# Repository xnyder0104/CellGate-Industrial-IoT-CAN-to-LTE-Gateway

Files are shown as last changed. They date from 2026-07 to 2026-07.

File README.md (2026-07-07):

# CellGate: Industrial IoT CAN-to-LTE Gateway

## Project Overview

This project is a compact, reliable, and manufacturable 2-layer custom PCB designed to bridge physical CAN bus networks with cloud infrastructure via cellular telemetry. Operating in harsh embedded environments, such as automotive engine bays or industrial factory floors, requires highly robust hardware. Power fluctuations, electrical noise, and Electrostatic Discharge (ESD) events can easily destroy standard development boards or cause critical communication failures.

To overcome these challenges, CellGate utilizes an STM32 ARM Cortex-M0+ microcontroller paired with a Quectel EC200U LTE Cat-1 module to handle high-speed data processing and transmission. The board integrates an industrial power path, strictly isolated voltage domains, multi-stage hardware protection, and a seamless load-sharing battery backup system, ensuring uninterrupted diagnostic data flow.

## Key Features & Engineering Highlights

* **Advanced Power Path Management:** Implements a PMV65XP MOSFET-based load-sharing architecture that automatically and seamlessly switches between a high-voltage external DC input (up to 40V) and a Lithium-ion battery backup without resetting the system.
* **Strict Voltage Domain Isolation:** A TXB0104 bidirectional logic level shifter protects the sensitive 1.8V Quectel silicon from the 3.3V STM32 logic signals, enabling safe, high-speed full-duplex UART transmission.
* **Fail-Safe Boot Design:** Integrates a hardware-level 10k-ohm pull-down resistor on the STM32 BOOT0 (PA14) pin to prevent the MCU from accidentally entering DFU Bootloader Mode due to ambient electrical noise during battery-only field operation.
* **Multi-Stage ESD Armor:** Deploys hardware protection across all external interfaces, including PESD2CAN TVS diodes on the differential bus lines and USBLC6 protection on the Type-C port.
* **Selectable Bus Termination:** Includes a physical jumper header for selectable 120-ohm CAN bus termination, making the board adaptable for end-of-line or mid-bus installations.
* **Comprehensive Diagnostic UI:** A dedicated 9-LED onboard panel provides immediate visual debugging for Main Power, Battery Charging, Battery Full, MCU Status, LTE Network Status, GPS Fix, CAN Activity, UART Activity, and Hardware Errors/Faults.

## Hardware Architecture & Working Principle

### 1. Power Supply & Battery Protection (+V_SYS)
* **HV Step-Down:** An LMR14030 buck converter steps down raw industrial inputs (up to 40V) to a stable 5V rail.
* **Voltage Regulation:** The master +V_SYS net feeds two independent LDOs: an AMS1117 generating the 3.3V MCU domain, and a TLV70218 generating the 1.8V modem reference domain.
* **Battery Circuitry:** A TP4056 linear charger manages Li-ion charging. It is paired with a strictly low-side DW01A controller and dual FS8205A MOSFETs, which continuously monitor the cell and isolate the battery ground instantly if over-charge, over-discharge, or a dead-short is detected.

### 2. Core Processing & Connectivity
* **Microcontroller Logic:** The STM32G0B1CBT6 handles all data preprocessing, CAN-to-UART conversion, and LED status mapping. 
* **Cellular & GNSS:** The Quectel EC200U module executes AT commands for LTE telemetry and GNSS location tracking. It is powered directly from the high-current battery rail (+V_BAT) to sustain 2-Amp transmission bursts safely.
* **CAN Interface:** An SN65HVD230 transceiver safely translates high-voltage automotive differential CAN signals down to the 3.3V logic level required by the STM32.

### 3. Debugging & Firmware Interfaces
* **SWD Programming:** Standard 5-pin SWD interface (SWDIO, SWCLK, NRST, +3.3V, GND) for flashing the STM32.
* **Hardware UART:** An exposed 4-pin hardware UART header operating strictly at 1.8V (VDD_EXT) for direct, low-level Quectel modem diagnostics.
* **USB Type-C:** Directly exposes the EC200U USB interface for cellular firmware upgrades and advanced module diagnostics.

## PCB Layout & Manufacturing Strategy

The board was meticulously routed as a 2-layer PCB, optimizing for low parasitic inductance, signal integrity, and manufacturability:

* **Solid Ground Plane:** The entire bottom layer is maintained as an unbroken solid copper ground plane to absorb the massive switching noise of the LMR14030 buck converter and provide a clean return path for RF signals.
* **Bottom-Layer Decoupling:** To minimize trace length and parasitic inductance, critical decoupling capacitors for the STM32 and Quectel EC200U are placed directly underneath the component pins on the bottom layer, fed by localized via stitching.
* **45-Degree Mitered Routing:** All high-speed data lines (6-mil trace width) utilize clean 45-degree cornering, avoiding 90-degree right angles and acute acid traps to ensure perfect chemical etching during manufacturing.
* **RF Trace Geometry:** 50-ohm controlled impedance traces are routed cleanly from the modem RF pads directly to the U.FL edge connectors, completely avoiding vias to prevent signal reflection.

## Applications

* Heavy machinery and fleet management telemetry (CAN bus diagnostics).
* Remote industrial equipment monitoring and predictive maintenance.
* Standalone IoT sensor gateways for off-grid environmental tracking.
* High-reliability telemetry nodes requiring uninterruptible power supplies (UPS).

## Future Scope

* **Mechanical Enclosure Design:** Utilizing the exported 3D .step files to design a custom, IP67-rated waterproof housing for harsh outdoor deployments.
* **Firmware Over-The-Air (FOTA):** Implementing a custom MCU bootloader to download, verify, and flash firmware updates seamlessly via the Quectel LTE connection.
* **Onboard Sensor Expansion:** Integrating standard I2C/SPI environmental sensors (e.g., temperature, humidity, accelerometer) directly onto the motherboard for localized physical diagnostics.

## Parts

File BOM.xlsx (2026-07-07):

Reference Designators | Quantity | Description | Package | Value | Top/Bottom
 | 1 | Board | Board
C1, C25 | 2 | Capacitor - Generic | CAPC1005X60 | 10uF | Top
C23, C24, C26 | 3 | Capacitor - Generic | CAPC1005X61 | 10uF | Bottom
C2 | 1 | Capacitor - Generic | CAPC1608X85 | 100uF | Bottom
C3 | 1 | Capacitor - Generic | CAPC1608X85 | 100nf | Bottom
C4 | 1 | Capacitor - Generic | CAPC1608X85 | 33pF | Bottom
C5 | 1 | Capacitor - Generic | CAPC1608X85 | 10pF | Bottom
C22 | 1 | Capacitor - Generic | CAPC1005X60 | 0.1uF | Bottom
C6 | 1 | Capacitor - Generic | CAPC1005X60 | 0.1uF | Top
C7 | 1 | Capacitor - Generic | CAPC1005X60 | 22uF | Top
C8 | 1 | Capacitor - Generic | CAPC1005X60 | 0.01uF | Top
C9, C10, C13, C14 | 4 | Capacitor - Generic | CAPC1005X60 | NC | Top
C11 | 1 | Capacitor - Generic | CAPC1005X60 | 1uF | Bottom
C12 | 1 | Capacitor - Generic | CAPC1005X60 | 2.2uF | Bottom
C15, C16, C18 | 3 | Capacitor - Generic | CAPC1005X60 | 100nF | Bottom
C17, C20, C21 | 3 | Capacitor - Generic | CAPC1005X61 | 100nF | Top
C19 | 1 | Capacitor - Generic | CAPC1005X60 | 4.7uF | Bottom
D1, D5, D7, D8, D9, D10, D11 | 7 | Green LED - Generic | LEDC1608X65N_RND-G | CHIP-ROUND-G_0603 | Top
D2, D12 | 2 | Red LED - Generic | LEDC1608X65N_RND-R | CHIP-ROUND-R_0603 | Top
D3 | 1 | Schottky Diode | SS26 | SS26 | Top
D13 | 1 | Schottky Diode | SS26 | SS26 | Bottom
D4 | 1 | 600-watt TVS diode | DIOM5436X261N | SMBJ48A | Top
D6 | 1 | B340A-13-F | DIOM5226X240N | B340A-13-F | Top
F1 | 1 | Polymeric positive temperature coefficient (PPTC) resettable fuse | FUSE_1812L05060_LTF | 1812L050FUSE | Top
J1, J3 | 2 | RF connector receptacle | HIROSE_U.FL-R-SMT(10) | U.FL-R-SMT(10) | Top
J2 | 1 | Female USB Type-C receptacle | SHOUHAN_TYPE-C_16PIN_2MD_(073) | TYPE-C | Top
J4 | 1 | micro SIM card connector | GCT_SIM7100-6-1-15-00-A_REVC2 | SIM7100-6-1-15-00-A_REVC2 | Top
JP1 | 1 | Pin Header | 1X04 | PINHD-1X4 | Top
JP2 | 1 | Pin Header | 1X05 | PINHD-1X5 | Top
JP3 | 1 | Pin Header | 1X02 | PINHD-1X2 | Top
L1 | 1 | Bourns SRN8040 Series Type SMD Shielded Wire-wound SMD Inductor with a Ferrite Core, 10 uH +/-20% Semi-Shielded 3.1A Idc | SRN8040100M | SRN8040-100M | Top
P1, P2 | 2 | 2-pin screw terminal | TE_282837-2 | 282837-2 | Top
Q1 | 1 | NPN BJT | TO92127P495H495-3 | 2N3904 | Top
Q2 | 1 | N-channel MOSFET | SOT-23-6L_TCP | FS8205ASOT-23-6L_TCP | Bottom
Q3 | 1 | P-channel MOSFET | SOT95P230X110-3N | PMV65XP,215 | Bottom
R1, R2, R6, R13, R15, R16, R17, R18, R19, R21 | 10 | Resistor Fixed - ANSI | RESC1005X40 | 1k | Top
R3 | 1 | Resistor Fixed - ANSI | RESC1005X40 | 68k | Top
R4 | 1 | Resistor Fixed - ANSI | RESC1005X40 | 12k | Top
R5, R7 | 2 | Resistor Fixed - ANSI | RESC1005X40 | 100k | Top
R25 | 1 | Resistor Fixed - ANSI | RESC1005X41 | 100k | Bottom
R14, R22, R26 | 3 | Resistor Fixed - ANSI | RESC1005X40 | 10k | Top
R8 | 1 | Resistor Fixed - ANSI | RESC1005X41 | 10k | Bottom
R11 | 1 | Resistor Fixed - ANSI | RESC1005X40 | 5.1k | Top
R9 | 1 | Resistor Fixed - ANSI | RESC1005X41 | 5.1k | Bottom
R10, R12 | 2 | Resistor Fixed - ANSI | RESC1005X40 | 0 | Top
R20 | 1 | Resistor Fixed - ANSI | RESC1005X40 | 100 | Top
R23 | 1 | Resistor Fixed - ANSI | RESC1005X40 | 120 | Top
R24 | 1 | Resistor Fixed - ANSI | RESC1005X40 | 1.2k | Bottom
S1 | 1 | ESD Protection for CAN | DIO_PESD2CAN,215 | PESD2CAN,215 | Top
U1 | 1 | Step-down (buck) voltage regulator | SOIC127P600X170-9N | LMR14030SDDAR | Top
U2 | 1 | ESD Protection for USB | SOT95P280X145-6N | USBLC6-2SC6 | Bottom
U3 | 1 | TLV70218DBVR | SOT95P280X145-5N | TLV70218DBVR | Bottom
U4 | 1 | EC200U | XCVR_EC200UCNAA-N05-SGNSA | EC200UCNAA-N05-SGNSA | Top
U5 | 1 | STM32 | LQFP48_STM32G0B1CBT_STM | STM32G0B1CBT6LQFP48 | Top
U6 | 1 | Battery protection IC | SOT95P280X145-6N | DW01A | Bottom
U7 | 1 | 4-bit bidirectional voltage-level translator | S-PVQFN-N14 | TXB0104RGY | Bottom
U8 | 1 | 3.3V CAN bus transceiver | SOIC127P599X175-8N | SN65HVD230 | Top
U9 | 1 | Linear charger IC | SOP127P600X175-9N | TP4056 | Bottom
U10 | 1 | Linear voltage regulator IC that steps down a higher DC voltage (up to 15V) to a stable, fixed 3.3V output, capable of supplying up to 1A of current | SOT229P700X180-4N | AMS1117-3.3 | Bottom

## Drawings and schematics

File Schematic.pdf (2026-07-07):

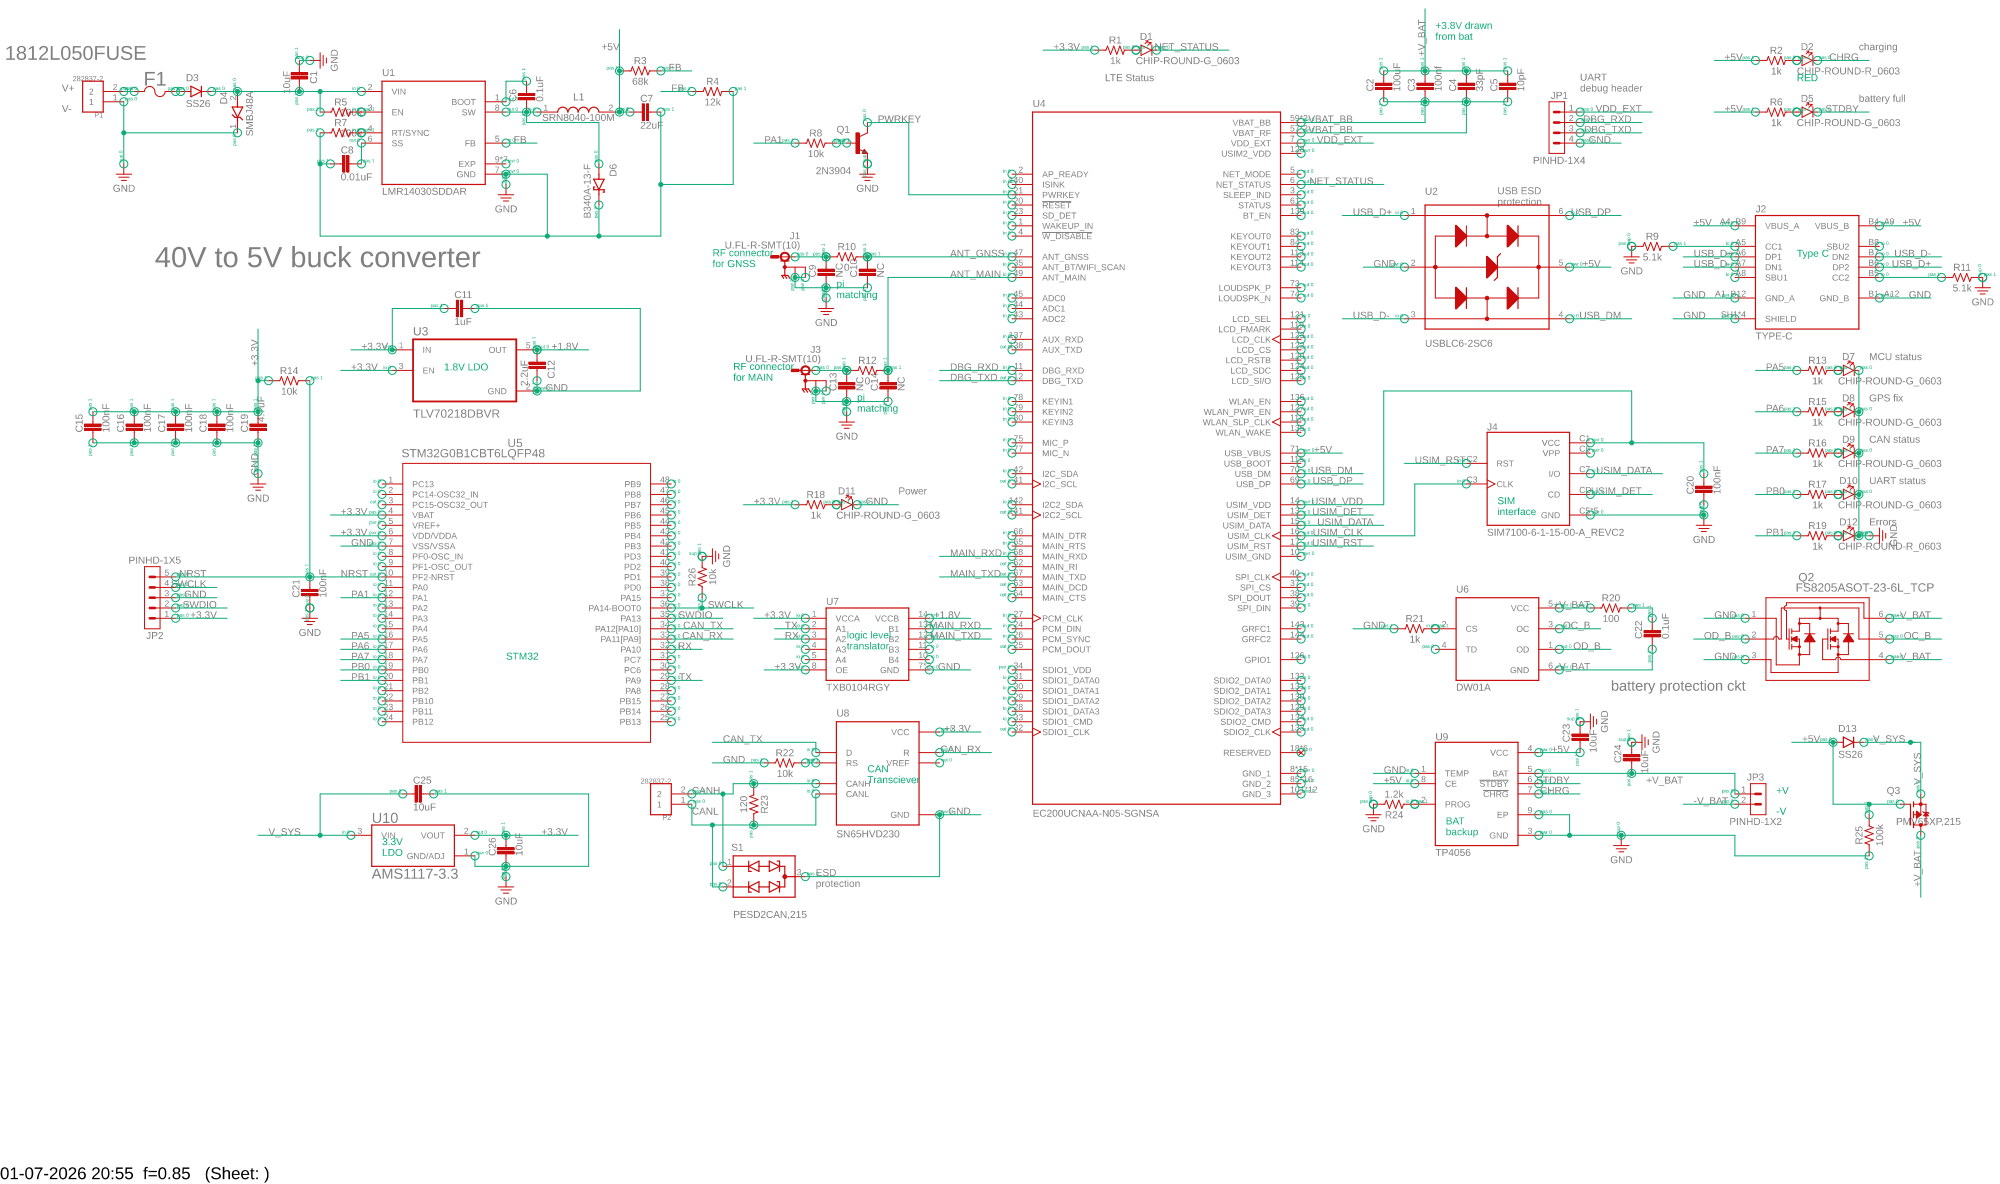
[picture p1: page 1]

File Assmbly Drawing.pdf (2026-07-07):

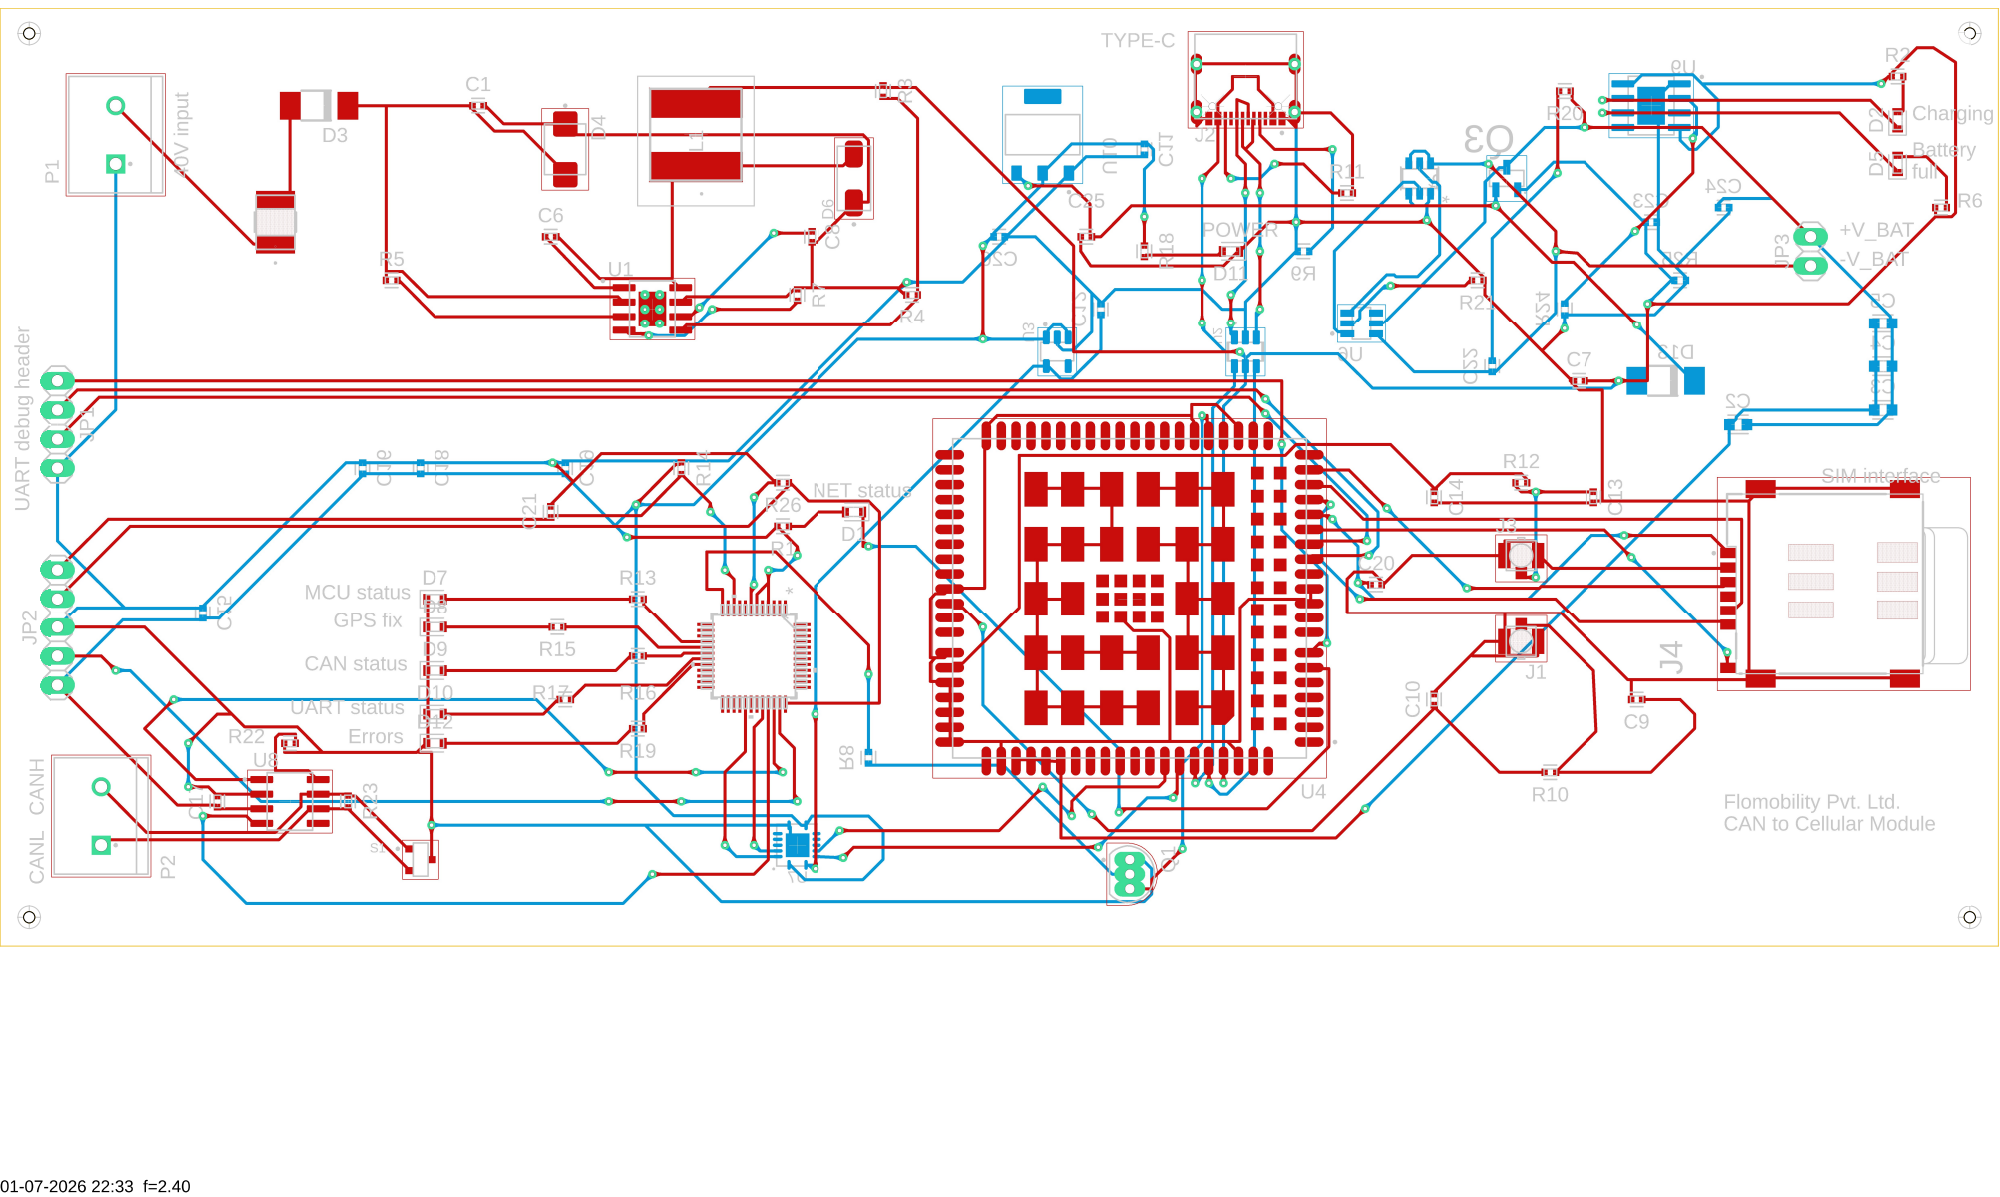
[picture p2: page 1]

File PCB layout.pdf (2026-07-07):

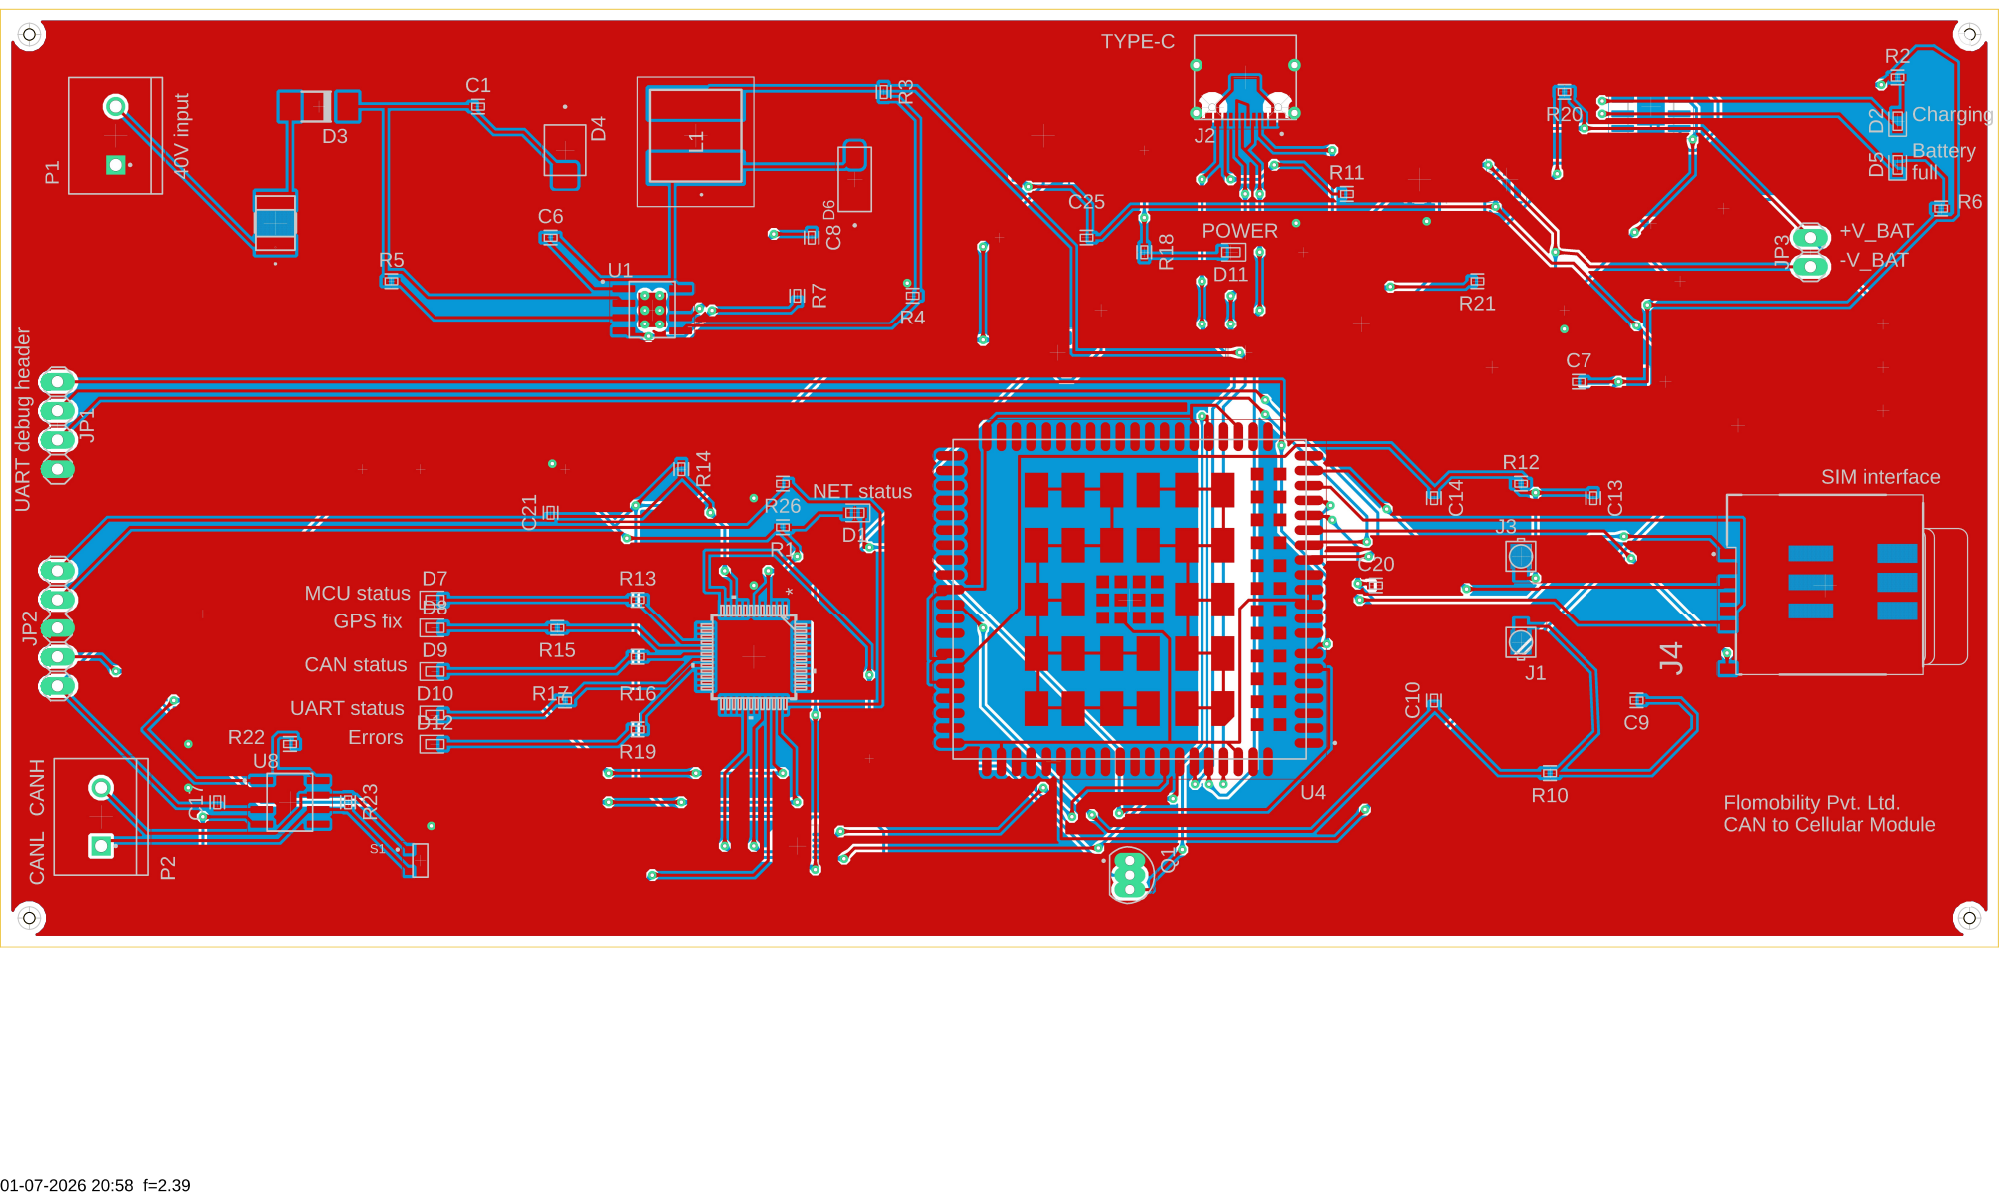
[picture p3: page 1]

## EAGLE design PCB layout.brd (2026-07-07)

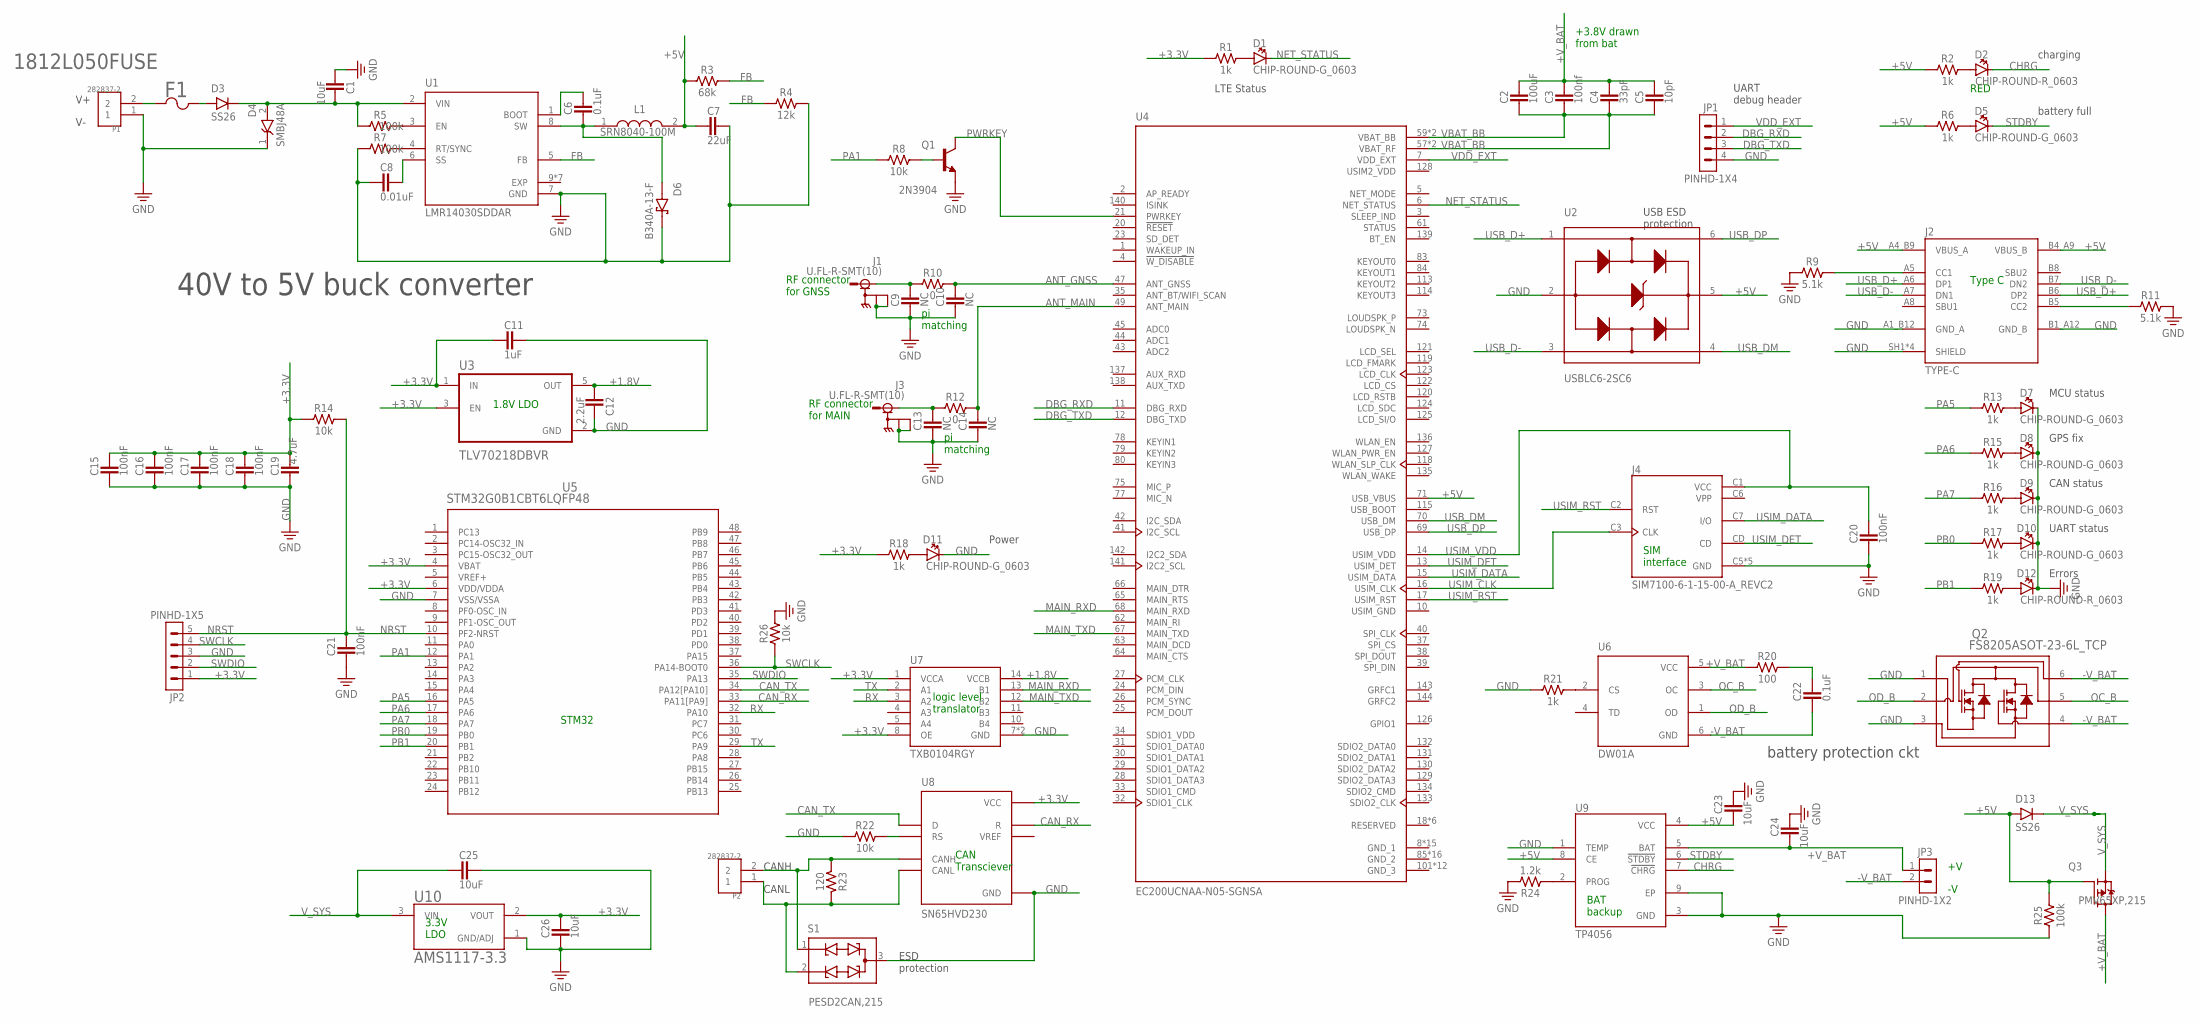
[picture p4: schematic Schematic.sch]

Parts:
C1, C23, C24, C25, C26: 10uF; CAPC1005X60
C2: 100uF; CAPC1608X85
C3: 100nf; CAPC1608X85
C4: 33pF; CAPC1608X85
C5: 10pF; CAPC1608X85
C6, C22: 0.1uF; CAPC1005X60
C7: 22uF; CAPC1005X60
C8: 0.01uF; CAPC1005X60
C9, C10, C13, C14: NC; CAPC1005X60
C11: 1uF; CAPC1005X60
C12: 2.2uF; CAPC1005X60
C15, C16, C17, C18, C20, C21: 100nF; CAPC1005X60
C19: 4.7uF; CAPC1005X60
D1, D5, D7, D8, D9, D10, D11: CHIP-ROUND-G_0603; LEDC1608X65N_RND-G
D2, D12: CHIP-ROUND-R_0603; LEDC1608X65N_RND-R
D3, D13: SS26
D4: SMBJ48A; DIOM5436X261N
D6: B340A-13-F; DIOM5226X240N
F1: 1812L050FUSE; FUSE_1812L05060_LTF
J1, J3: U.FL-R-SMT(10); HIROSE_U.FL-R-SMT(10)
J2: TYPE-C; SHOUHAN_TYPE-C_16PIN_2MD_(073)
J4: SIM7100-6-1-15-00-A_REVC2; GCT_SIM7100-6-1-15-00-A_REVC2
JP1: PINHD-1X4; 1X04
JP2: PINHD-1X5; 1X05
JP3: PINHD-1X2; 1X02
L1: SRN8040-100M; SRN8040100M
P1, P2: 282837-2; TE_282837-2
Q1: 2N3904; TO92127P495H495-3
Q2: FS8205ASOT-23-6L_TCP; SOT-23-6L_TCP
Q3: PMV65XP,215; SOT95P230X110-3N
R1, R2, R6, R13, R15, R16, R17, R18, R19, R21: 1k; RESC1005X40
R3: 68k; RESC1005X40
R4: 12k; RESC1005X40
R5, R7, R25: 100k; RESC1005X40
R8, R14, R22, R26: 10k; RESC1005X40
R9, R11: 5.1k; RESC1005X40
R10, R12: 0; RESC1005X40
R20: 100; RESC1005X40
R23: 120; RESC1005X40
R24: 1.2k; RESC1005X40
S1: PESD2CAN,215; DIO_PESD2CAN,215
U1: LMR14030SDDAR; SOIC127P600X170-9N
U2: USBLC6-2SC6; SOT95P280X145-6N
U3: TLV70218DBVR; SOT95P280X145-5N
U4: EC200UCNAA-N05-SGNSA; XCVR_EC200UCNAA-N05-SGNSA
U5: STM32G0B1CBT6LQFP48; LQFP48_STM32G0B1CBT_STM
U6: DW01A; SOT95P280X145-6N
U7: TXB0104RGY; S-PVQFN-N14
U8: SN65HVD230; SOIC127P599X175-8N
U9: TP4056; SOP127P600X175-9N
U10: AMS1117-3.3; SOT229P700X180-4N

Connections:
+1.8V: C12.2, U3.5 (OUT), U7.14 (VCCB)
+3.3V: C11.2, C15.1, C16.1, C17.1, C18.1, C19.1, C26.1, JP2.1, R1.1, R14.1, R18.1, U3.1 (IN), U3.3 (EN), U5.4 (VBAT), U5.6 (VDD/VDDA), U7.1 (VCCA), U7.8 (OE), U8.3 (VCC), U10.2 (VOUT)
+5V: C7.2, C23.2, D13.A, J2.A4_B9 (VBUS_A), J2.B4_A9 (VBUS_B), L1.2, Q3.1 (G), R2.1, R3.1, R6.1, R25.2, U2.5 (VBUS), U4.71 (USB_VBUS), U9.4 (VCC), U9.8 (CE)
+V_BAT: C2.1, C3.1, C4.1, C5.1, C24.2, JP3.1, Q3.3 (D), R20.1, U6.5 (VCC), U9.5 (BAT)
-V_BAT: C22.2, JP3.2, Q2.4, Q2.6, U6.6 (GND)
ANT_GNSS: C10.1, R10.2, U4.47 (ANT_GNSS)
ANT_MAIN: C14.1, R12.2, U4.49 (ANT_MAIN)
CANH: P2.2, R23.2, S1.1 (C1), U8.7 (CANH)
CAN_RX: U5.33 (PA11[PA9]), U8.4 (R)
CAN_TX: U5.34 (PA12[PA10]), U8.1 (D)
CHRG: D2.C, U9.7 (!CHRG)
DBG_RXD: JP1.2, U4.11 (DBG_RXD)
DBG_TXD: JP1.3, U4.12 (DBG_TXD)
EXP: U1.9 (EXP), U1.V1 (EXP), U1.V2 (EXP), U1.V3 (EXP), U1.V4 (EXP), U1.V5 (EXP), U1.V6 (EXP)
FB: R3.2, R4.1, U1.5 (FB)
GND: C1.2, C7.1, C8.2, C9.2, C10.2, C11.1, C12.1, C13.2, C14.2, C15.2, C16.2, C17.2, C18.2, C19.2, C20.2, C21.2, C23.1, C24.1, C25.1, C26.2, D4.1 (K), D6.C, D7.C, D8.C, D9.C, D10.C, D11.C, D12.C, J1.G1, J1.G2, J2.A1_B12 (GND_A), J2.B1_A12 (GND_B), J2.SH1 (SHIELD), J2.SH2 (SHIELD), J2.SH3 (SHIELD), J2.SH4 (SHIELD), J3.G1, J3.G2, J4.C5 (GND), J4.G1 (GND), J4.G2 (GND), J4.G3 (GND), J4.G4 (GND), JP1.4, JP2.3, P1.1, Q1.1 (E), Q2.1, Q2.3, R4.2, R7.1, R9.1, R11.2, R21.1, R22.1, R24.2, R25.1, R26.2, S1.3 (CC), U1.7 (GND), U2.2 (GND), U3.2 (GND), U5.7 (VSS/VSSA), U7.7 (GND), U7.THERMALPAD (GND), U8.2 (GND), U9.1 (TEMP), U9.3 (GND), U9.9 (EP), U10.1 (GND/ADJ)
GND_1: U4.8 (GND_1), U4.9 (GND_1), U4.19 (GND_1), U4.22 (GND_1), U4.36 (GND_1), U4.46 (GND_1), U4.48 (GND_1), U4.50 (GND_1), U4.51 (GND_1), U4.52 (GND_1), U4.53 (GND_1), U4.54 (GND_1), U4.56 (GND_1), U4.72 (GND_1), U4.76 (GND_1)
GND_2: U4.85 (GND_2), U4.86 (GND_2), U4.87 (GND_2), U4.88 (GND_2), U4.89 (GND_2), U4.90 (GND_2), U4.91 (GND_2), U4.92 (GND_2), U4.93 (GND_2), U4.94 (GND_2), U4.95 (GND_2), U4.96 (GND_2), U4.97 (GND_2), U4.98 (GND_2), U4.99 (GND_2), U4.100 (GND_2)
GND_3: U4.101 (GND_3), U4.102 (GND_3), U4.103 (GND_3), U4.104 (GND_3), U4.105 (GND_3), U4.106 (GND_3), U4.107 (GND_3), U4.108 (GND_3), U4.109 (GND_3), U4.110 (GND_3), U4.111 (GND_3), U4.112 (GND_3)
MAIN_RXD: U4.68 (MAIN_RXD), U7.13 (B1)
MAIN_TXD: U4.67 (MAIN_TXD), U7.12 (B2)
unnamed: Q1.2 (B), R8.2
unnamed: J2.A5 (CC1), R9.2
unnamed: J2.B5 (CC2), R11.1
unnamed: C9.1, J1.SIG, R10.1
unnamed: R24.1, U9.2 (PROG)
unnamed: D2.A, R2.2
unnamed: D5.A, R6.2
unnamed: C13.1, J3.SIG, R12.1
unnamed: R22.2, U8.8 (RS)
unnamed: F1.1, P1.2
unnamed: D3.A, F1.2
unnamed: C1.1, D3.C, D4.2 (A), R5.1, U1.2 (VIN)
unnamed: C6.1, U1.1 (BOOT)
unnamed: C6.2, D6.A, L1.1, U1.8 (SW)
unnamed: R5.2, U1.3 (EN)
unnamed: R7.2, U1.4 (RT/SYNC)
unnamed: C8.1, U1.6 (SS)
unnamed: R21.2, U6.2 (CS)
unnamed: D11.A, R18.2
unnamed: C22.1, R20.2
unnamed: P2.1, R23.1, S1.2 (C2), U8.6 (CANL)
unnamed: D1.A, R1.2
unnamed: D7.A, R13.2
unnamed: D8.A, R15.2
unnamed: D9.A, R16.2
unnamed: D10.A, R17.2
unnamed: D12.A, R19.2
NET_STATUS: D1.C, U4.6 (NET_STATUS)
NRST: C21.1, JP2.5, R14.2, U5.10 (PF2-NRST)
OC_B: Q2.5, U6.3 (OC)
OD_B: Q2.2, U6.1 (OD)
PA1: R8.1, U5.12 (PA1)
PA5: R13.1, U5.16 (PA5)
PA6: R15.1, U5.17 (PA6)
PA7: R16.1, U5.18 (PA7)
PB0: R17.1, U5.19 (PB0)
PB1: R19.1, U5.20 (PB1)
PWRKEY: Q1.3 (C), U4.21 (PWRKEY)
RX: U5.32 (PA10), U7.3 (A2)
SDIO1_VDD: U4.34 (SDIO1_VDD)
STDBY: D5.C, U9.6 (!STDBY)
SWCLK: JP2.4, R26.1, U5.36 (PA14-BOOT0)
SWDIO: JP2.2, U5.35 (PA13)
TX: U5.29 (PA9), U7.2 (A1)
USB_D+: J2.A6 (DP1), J2.B6 (DP2), U2.1 (I/O1_IN)
USB_D-: J2.A7 (DN1), J2.B7 (DN2), U2.3 (I/O2_IN)
USB_DM: U2.4 (I/O2_OUT), U4.70 (USB_DM)
USB_DP: U2.6 (I/O1_OUT), U4.69 (USB_DP)
USIM2_VDD: U4.128 (USIM2_VDD)
USIM_CLK: J4.C3 (CLK), U4.16 (USIM_CLK)
USIM_DATA: J4.C7 (I/O), U4.15 (USIM_DATA)
USIM_DET: J4.CD, U4.13 (USIM_DET)
USIM_GND: U4.10 (USIM_GND)
USIM_RST: J4.C2 (RST), U4.17 (USIM_RST)
USIM_VDD: C20.1, J4.C1 (VCC), U4.14 (USIM_VDD)
VBAT_BB: C2.2, C3.2, C4.2, C5.2, U4.57 (VBAT_RF), U4.58 (VBAT_RF), U4.59 (VBAT_BB), U4.60 (VBAT_BB)
VDD_EXT: JP1.1, U4.7 (VDD_EXT)
VPP: J4.C6 (VPP)
VREF+: U5.5 (VREF+)
V_SYS: C25.2, D13.C, Q3.2 (S), U10.3 (VIN)

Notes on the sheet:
1.8V LDO
logic level translator
CAN Transciever
STM32
Type C
RF connector for GNSS
pi matching
SIM interface
BAT backup
RED
RF connector for MAIN
+3.8V drawn from bat
3.3V LDO
ESD protection
40V to 5V buck converter
battery protection ckt
CANH
CANL
USB ESD protection
charging
battery full
Power
LTE Status
MCU status
GPS fix
CAN status
UART status
Errors
UART debug header

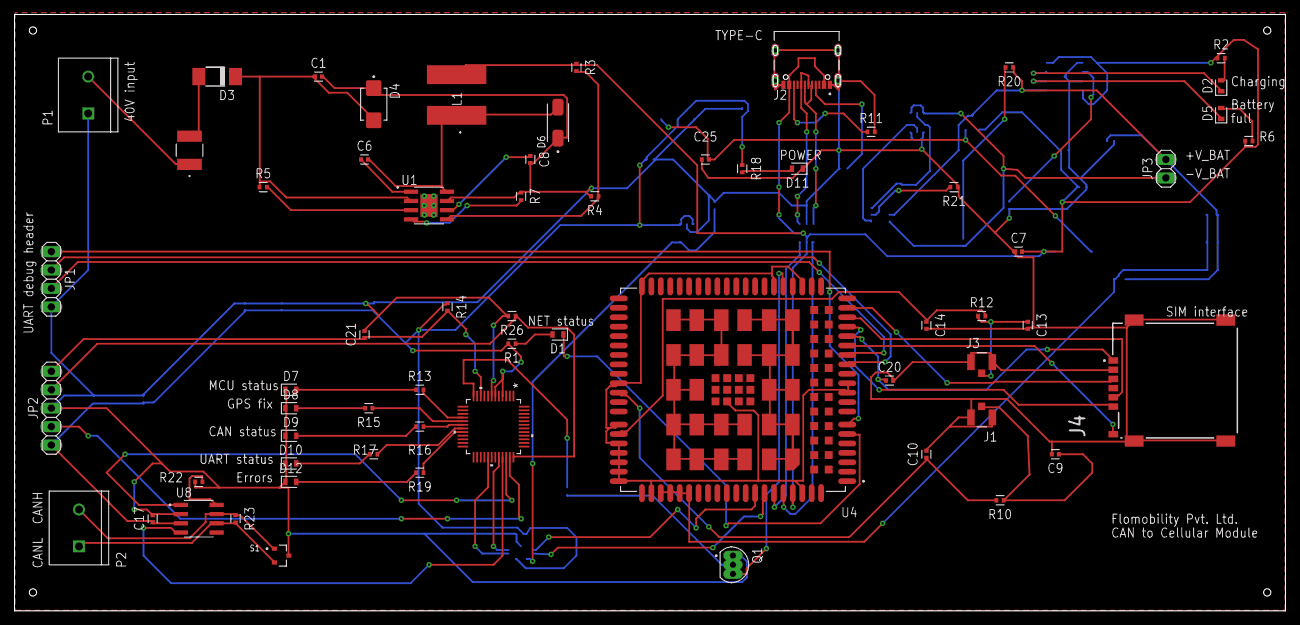
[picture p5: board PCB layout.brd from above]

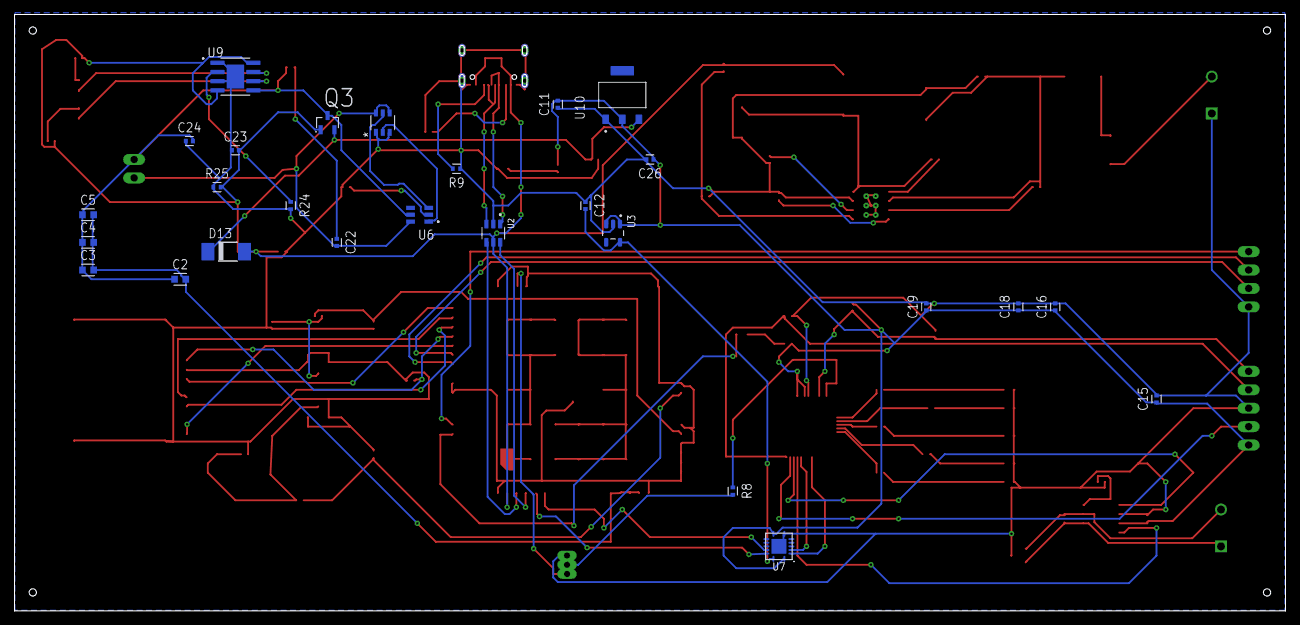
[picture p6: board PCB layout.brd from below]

Board: 2 copper layers, 175.2 x 82.2 mm, 90 parts (27 on the bottom side), 76 nets.

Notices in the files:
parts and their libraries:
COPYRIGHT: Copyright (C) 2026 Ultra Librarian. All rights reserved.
